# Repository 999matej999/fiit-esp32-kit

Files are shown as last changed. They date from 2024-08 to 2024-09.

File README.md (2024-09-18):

# FIIT ESP32 Kit
Board contains these components:
* 4x Buttons (needs internal pull-up resistor)
* 4x LED (red, yellow, green, blue)
* Programmable RGB LED
* Temperature & Humidity I<sup>2</sup>C Sensor AHT20
* Analog Light Sensor SFH320
* 2x QWIIC I<sup>2</sup>C connectors

For uploading code use USB UART by default.

## Pinout
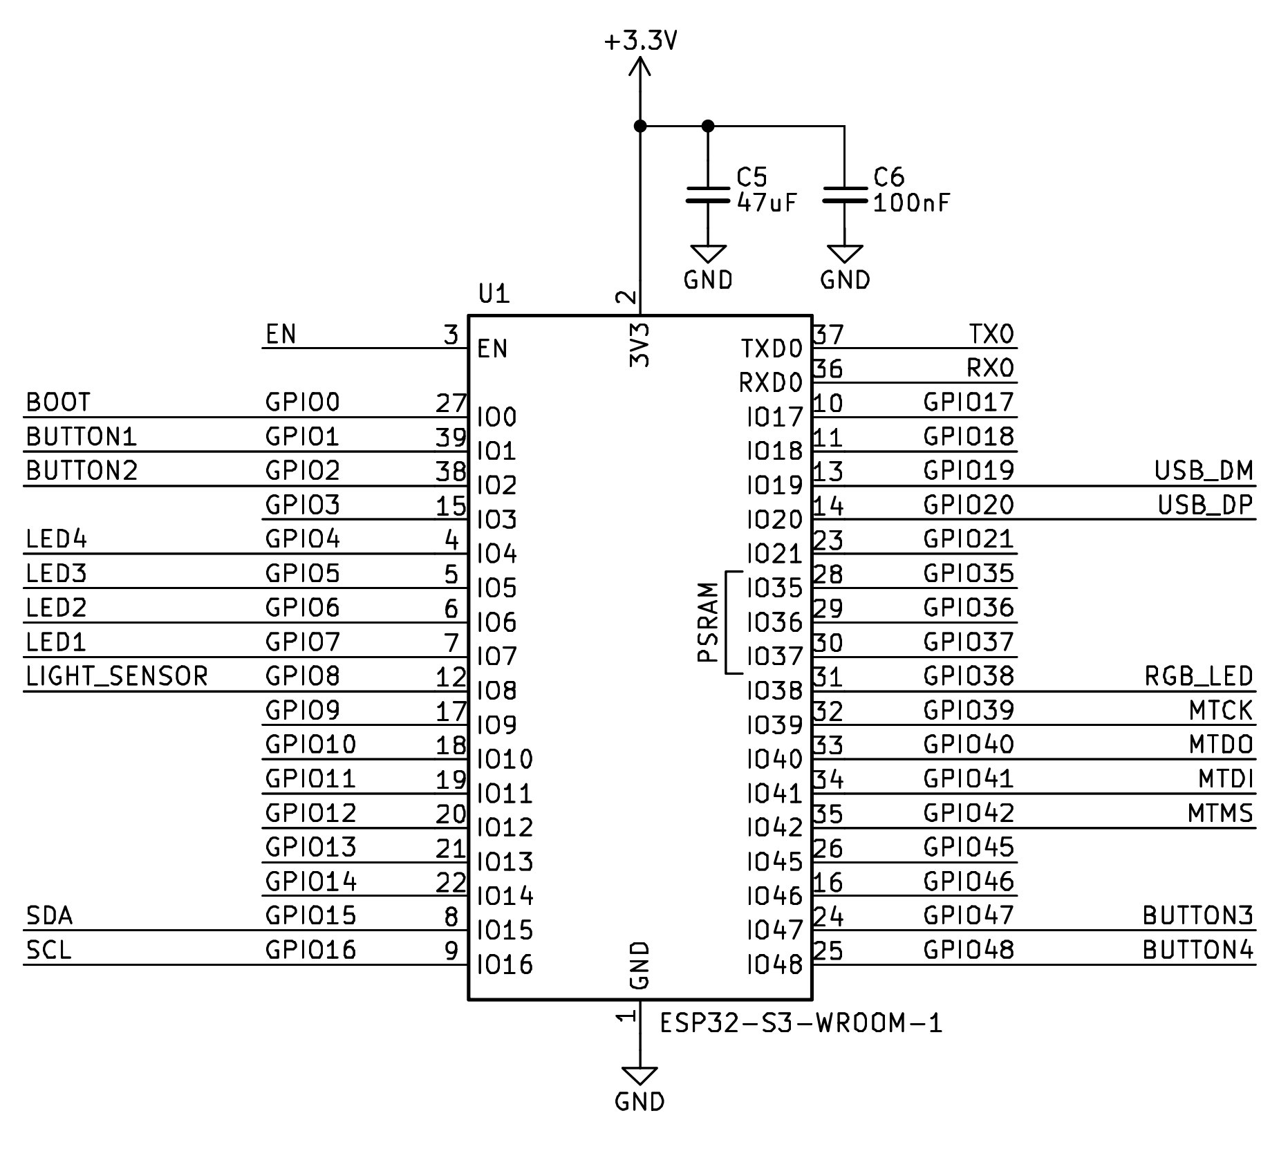
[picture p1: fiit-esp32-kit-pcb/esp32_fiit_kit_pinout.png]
pinout


GPIOX represents the pin marking, where X is the pin number that needs to be used in the Arduino IDE.

Please consider proper electrical connection to prevent electrical shortcuts.

## Arduino IDE
First of all ensure you have Arduino IDE and [ESP32 boards](https://randomnerdtutorials.com/installing-the-esp32-board-in-arduino-ide-windows-instructions/) properly installed.
Select board: ESP32S3 Dev Module
For basic examples use default configuration.

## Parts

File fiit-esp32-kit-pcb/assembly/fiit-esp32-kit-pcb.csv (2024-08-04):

Comment | Designator | Footprint | LCSC
22uF | C1,C2,C8,C9,C15 | Capacitor_SMD:C_0603_1608Metric | C59461
100uF | C11 | Capacitor_SMD:C_1206_3216Metric | C15008
1uF | C12,C13 | Capacitor_SMD:C_0603_1608Metric | C15849
100nF | C3,C4,C6,C10,C14,C16 | Capacitor_SMD:C_0603_1608Metric | C14663
47uF | C5 | Capacitor_SMD:C_0805_2012Metric | C16780
22pF | C7 | Capacitor_SMD:C_0603_1608Metric | C1653
RED | D1 | LED_SMD:LED_0805_2012Metric | C2295
YELLOW | D2,D10,D11 | LED_SMD:LED_0805_2012Metric | C2296
SK6812MINI | D12 | LED_SMD:LED_SK6812MINI_PLCC4_3.5x3.5mm_P1.75mm | C2886570
BLUE | D4 | LED_SMD:LED_0805_2012Metric | C2293
GREEN | D3,D5 | LED_SMD:LED_0805_2012Metric | C2297
PRTR5V0U2X | D6,D7 | Package_TO_SOT_SMD:SOT-143 | C5337179
BAT60B | D8,D9 | Diode_SMD:D_SOD-323 | C3018529
Conn_01x22_Pin | J1,J2 | Connector_PinHeader_2.54mm:PinHeader_1x22_P2.54mm_Vertical | C7430378
Conn_ARM_JTAG_SWD_10 | J3 | Connector_PinHeader_1.27mm:PinHeader_2x05_P1.27mm_Vertical_SMD
Conn_01x06_Pin | J4 | Connector_PinHeader_1.27mm:PinHeader_2x03_P1.27mm_Vertical_SMD
USB_C_Receptacle_USB2.0 | J5,J6 | Connector_USB:USB_C_Receptacle_G-Switch_GT-USB-7010ASV | C2927038
QWIIC - I2C | J7,J8 | Connector_JST:JST_SH_SM04B-SRSS-TB_1x04-1MP_P1.00mm_Horizontal | C160404
MPL2016S2R2 | L1 | FIIT_Kit:INDC2116X100N | C42215
MMDT3904 | Q1 | Package_TO_SOT_SMD:SOT-363_SC-70-6 | C3018510
SFH320 | Q2 | FIIT_Kit:TEMT6000X01 | C94098
100k | R1 | Resistor_SMD:R_0603_1608Metric | C25803
22.1k | R14 | Resistor_SMD:R_0603_1608Metric | C25961
47.5k | R15 | Resistor_SMD:R_0603_1608Metric | C23061
10k | R2,R6,R7,R12,R13,R16,R19 | Resistor_SMD:R_0603_1608Metric | C25804
4.99k | R3 | Resistor_SMD:R_0603_1608Metric | C23046
1.1k | R4 | Resistor_SMD:R_0603_1608Metric | C22764
2.4k | R5,R17,R18 | Resistor_SMD:R_0603_1608Metric | C22940
5.1k | R8,R9,R10,R11 | Resistor_SMD:R_0603_1608Metric | C23186
2.4k | RN1 | Resistor_SMD:R_Array_Convex_4x0603 | C425225
100R | RN2 | Resistor_SMD:R_Array_Convex_4x0603 | C425240
SPST NO | SW1,SW2,SW3,SW4,SW5 | Button_Switch_SMD:SW_SPST_PTS647_Sx38 | C318884
+5V | TP1 | TestPoint:TestPoint_Pad_D1.5mm
+3.3V | TP2 | TestPoint:TestPoint_Pad_D1.5mm
SDA | TP3 | TestPoint:TestPoint_Pad_D1.5mm
SCL | TP4 | TestPoint:TestPoint_Pad_D1.5mm
GND | TP5 | TestPoint:TestPoint_Pad_D1.5mm
SERIAL-RX | TP6 | TestPoint:TestPoint_Pad_D1.5mm
SERIAL-TX | TP7 | TestPoint:TestPoint_Pad_D1.5mm
ESP32-S3-WROOM-1 | U1 | RF_Module:ESP32-S3-WROOM-1 | C2913205
SY8089AAAC | U2 | Package_TO_SOT_SMD:TSOT-23-5 | C78988
CP2102N-Axx-xQFN28 | U3 | Package_DFN_QFN:QFN-28-1EP_5x5mm_P0.5mm_EP3.35x3.35mm | C964632
AHT20 | U4 | FIIT_Kit:AHT20 | C2757850

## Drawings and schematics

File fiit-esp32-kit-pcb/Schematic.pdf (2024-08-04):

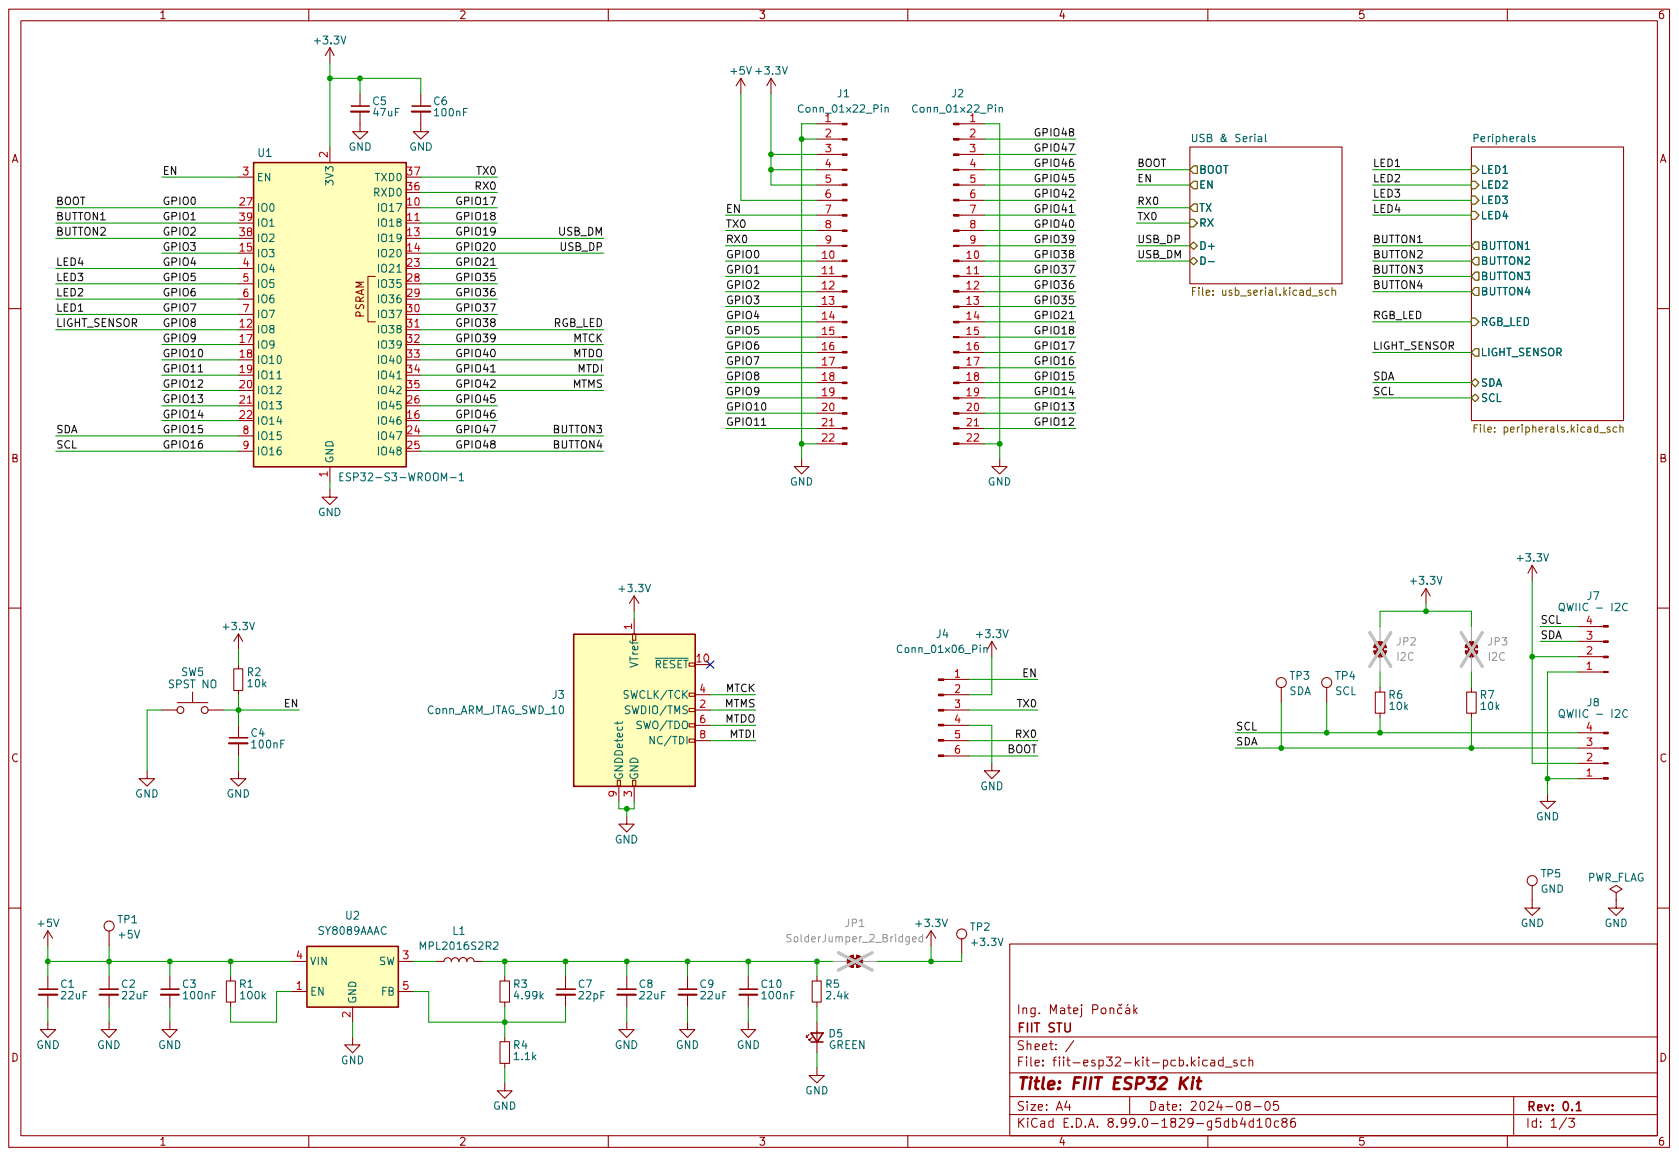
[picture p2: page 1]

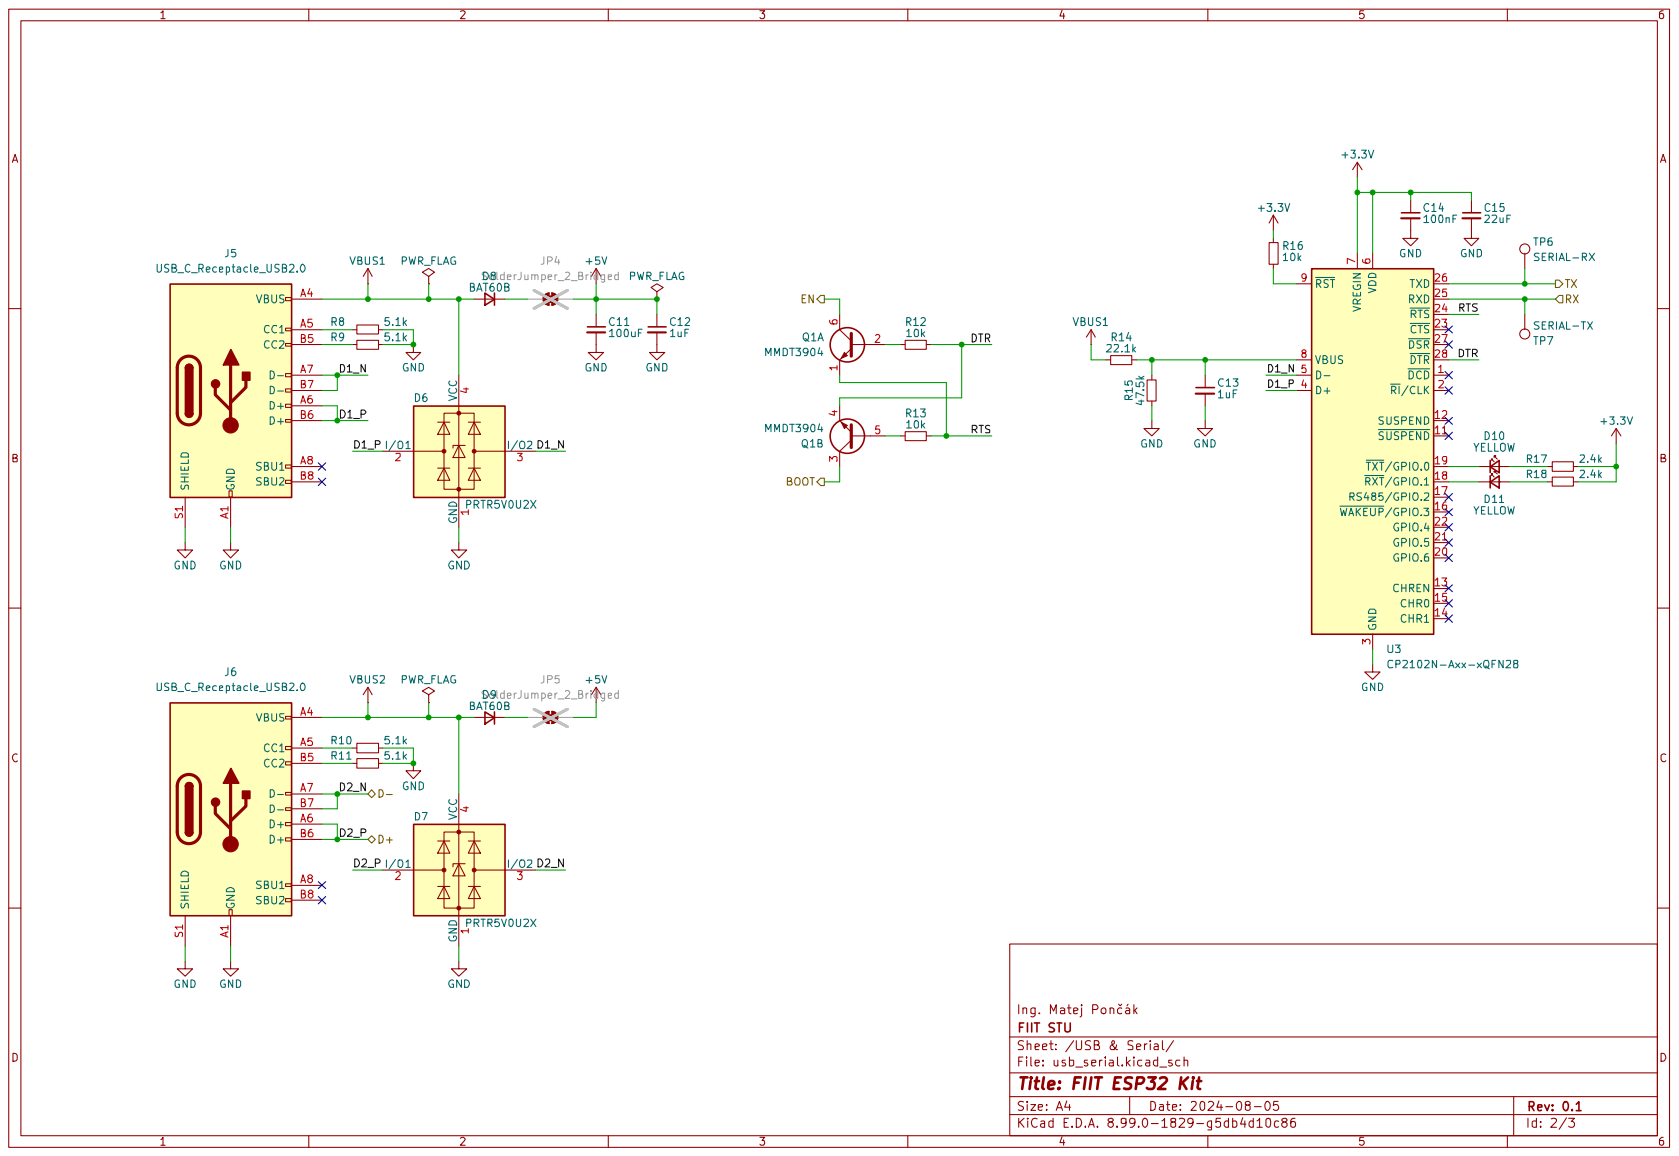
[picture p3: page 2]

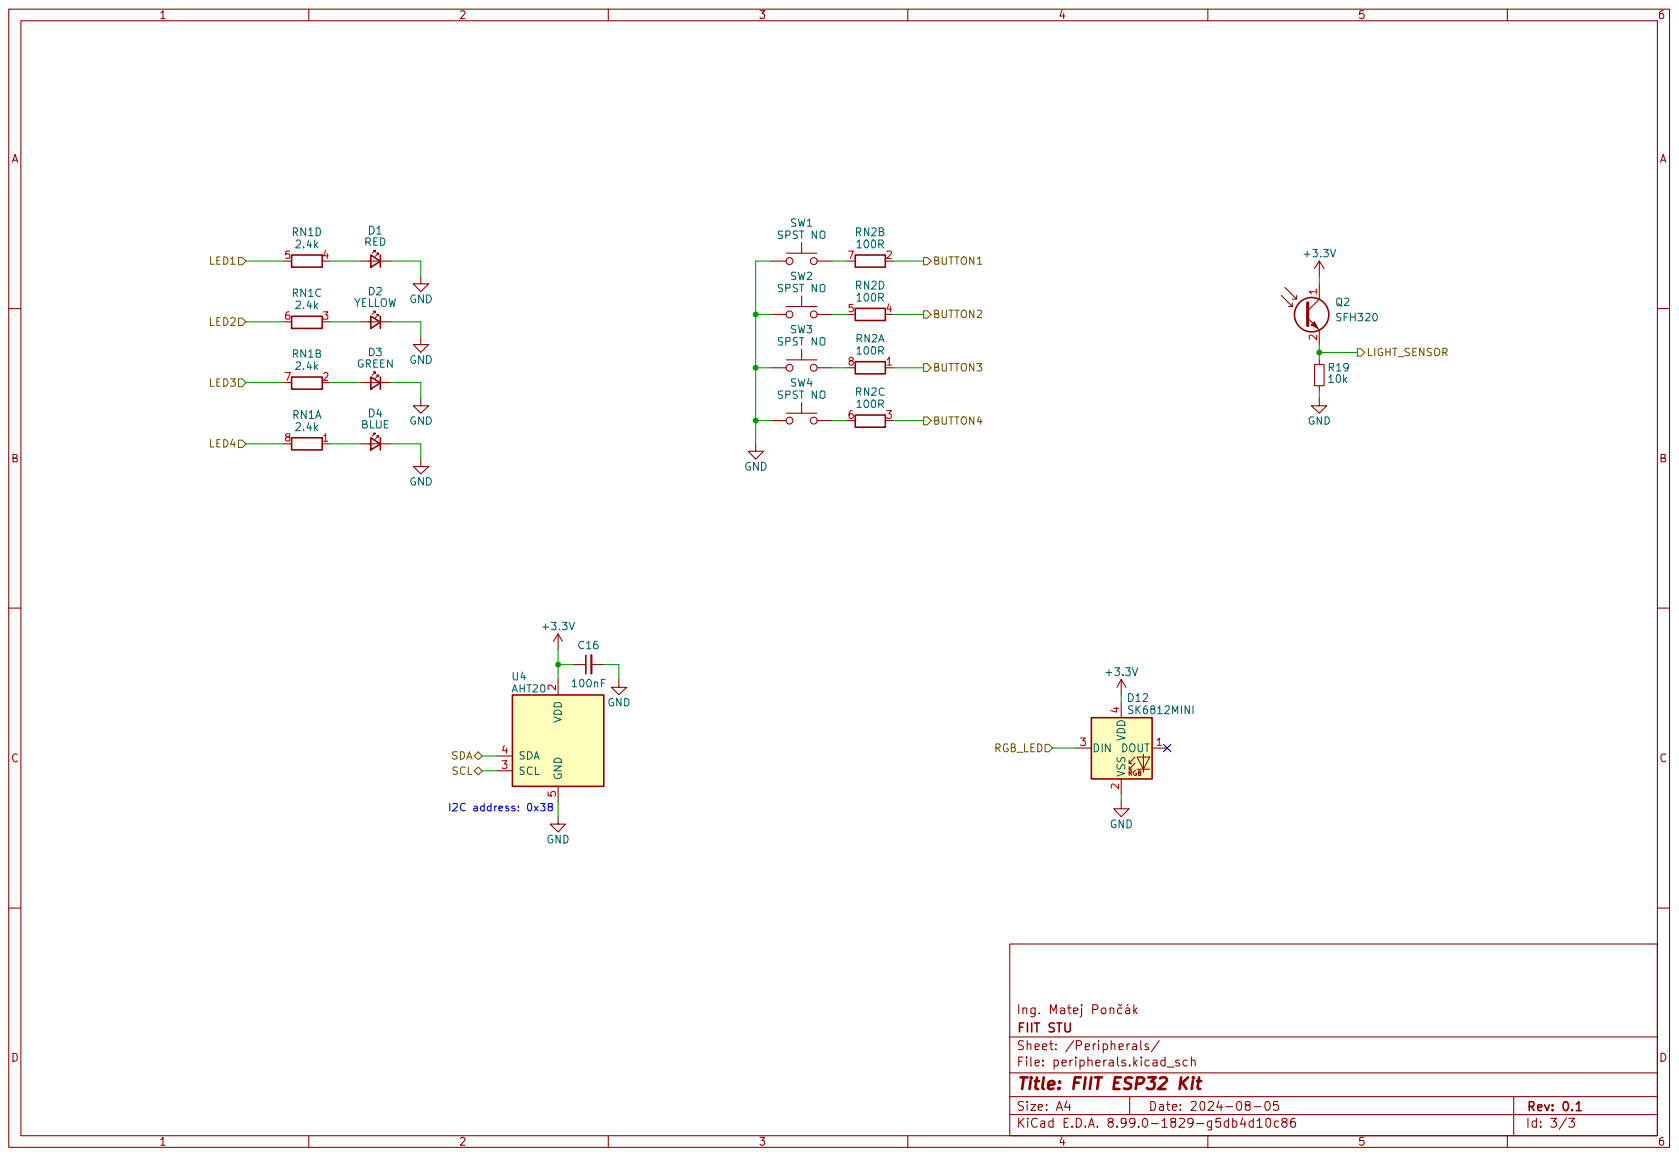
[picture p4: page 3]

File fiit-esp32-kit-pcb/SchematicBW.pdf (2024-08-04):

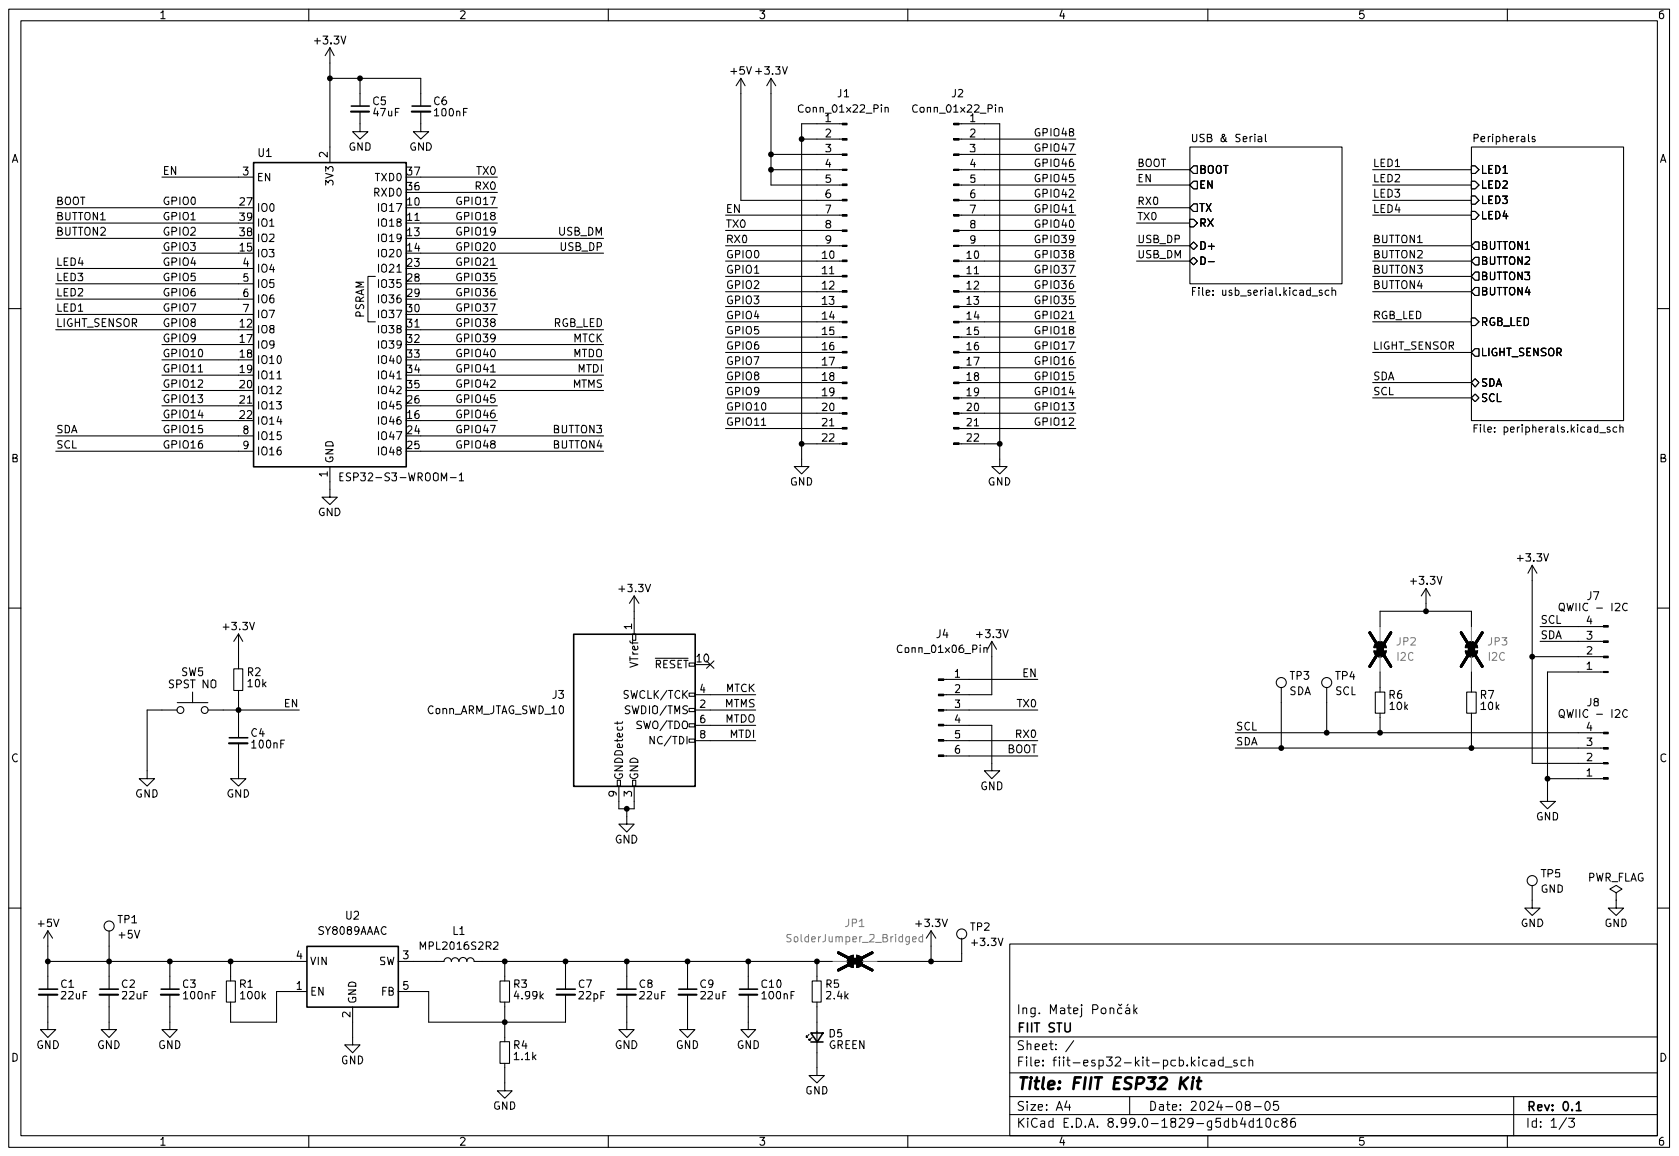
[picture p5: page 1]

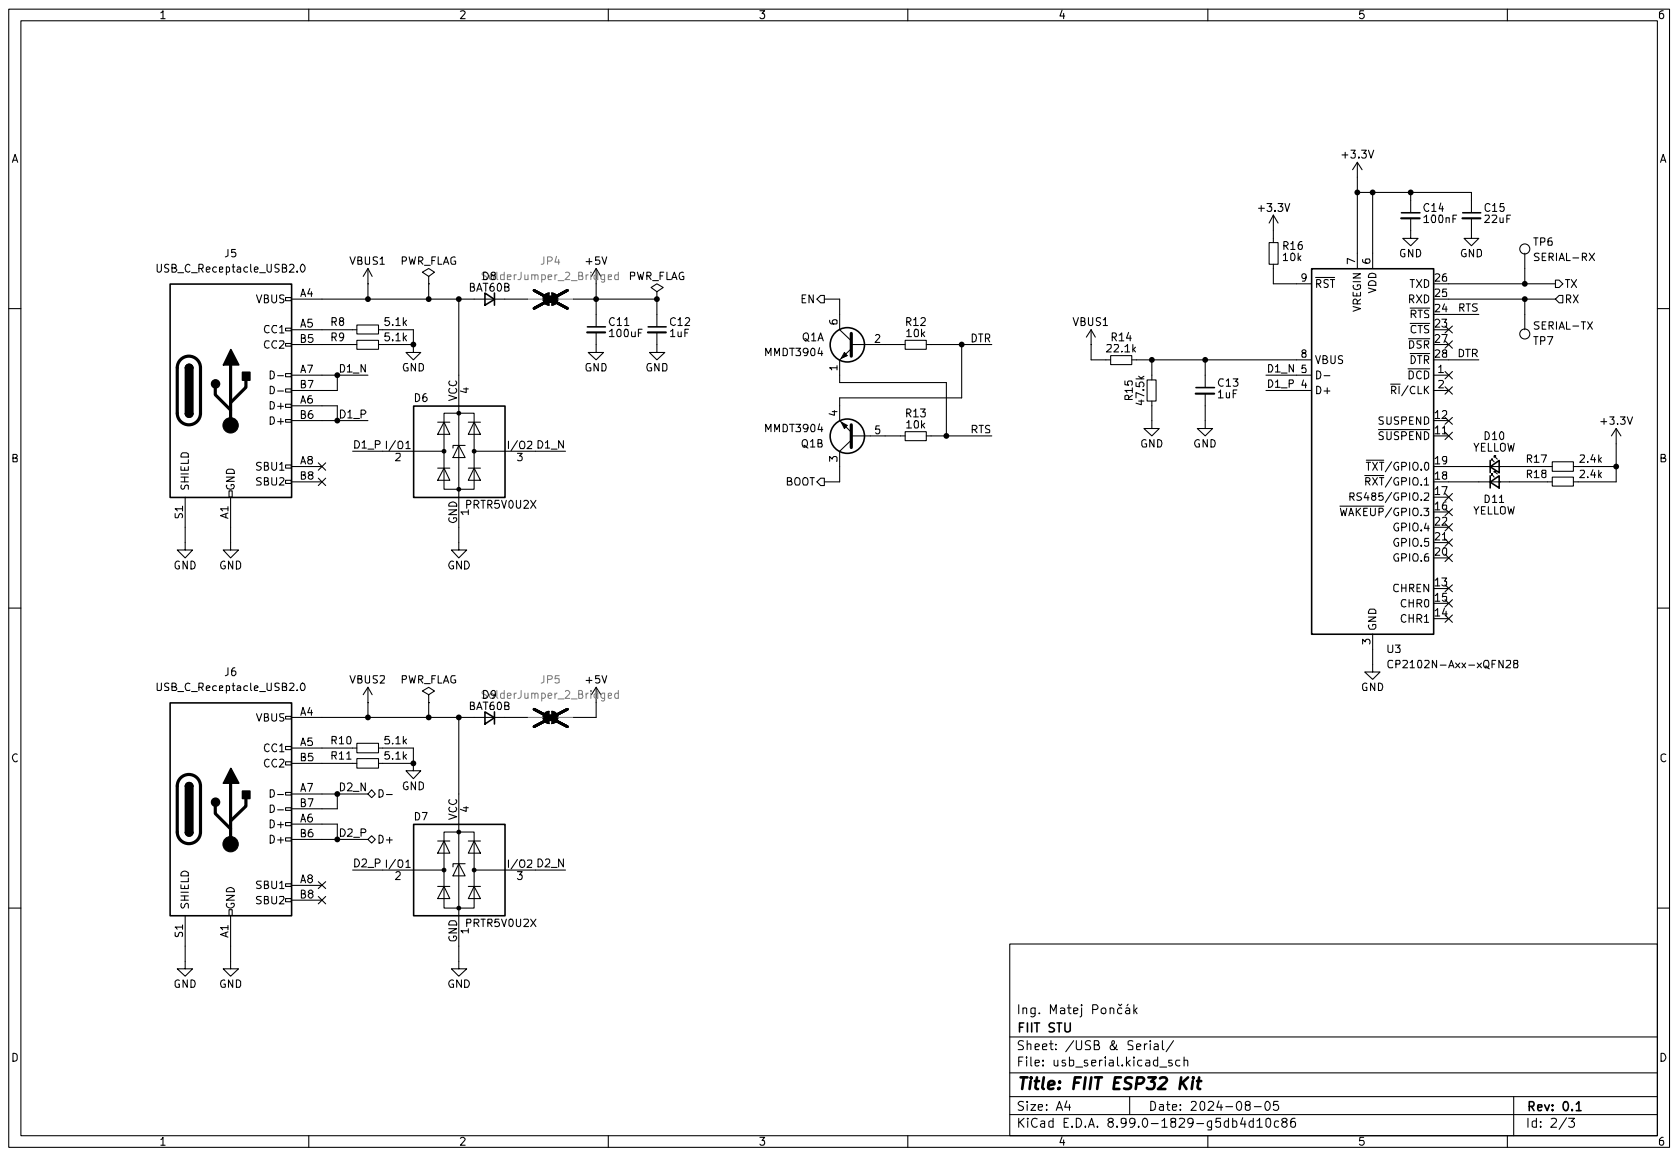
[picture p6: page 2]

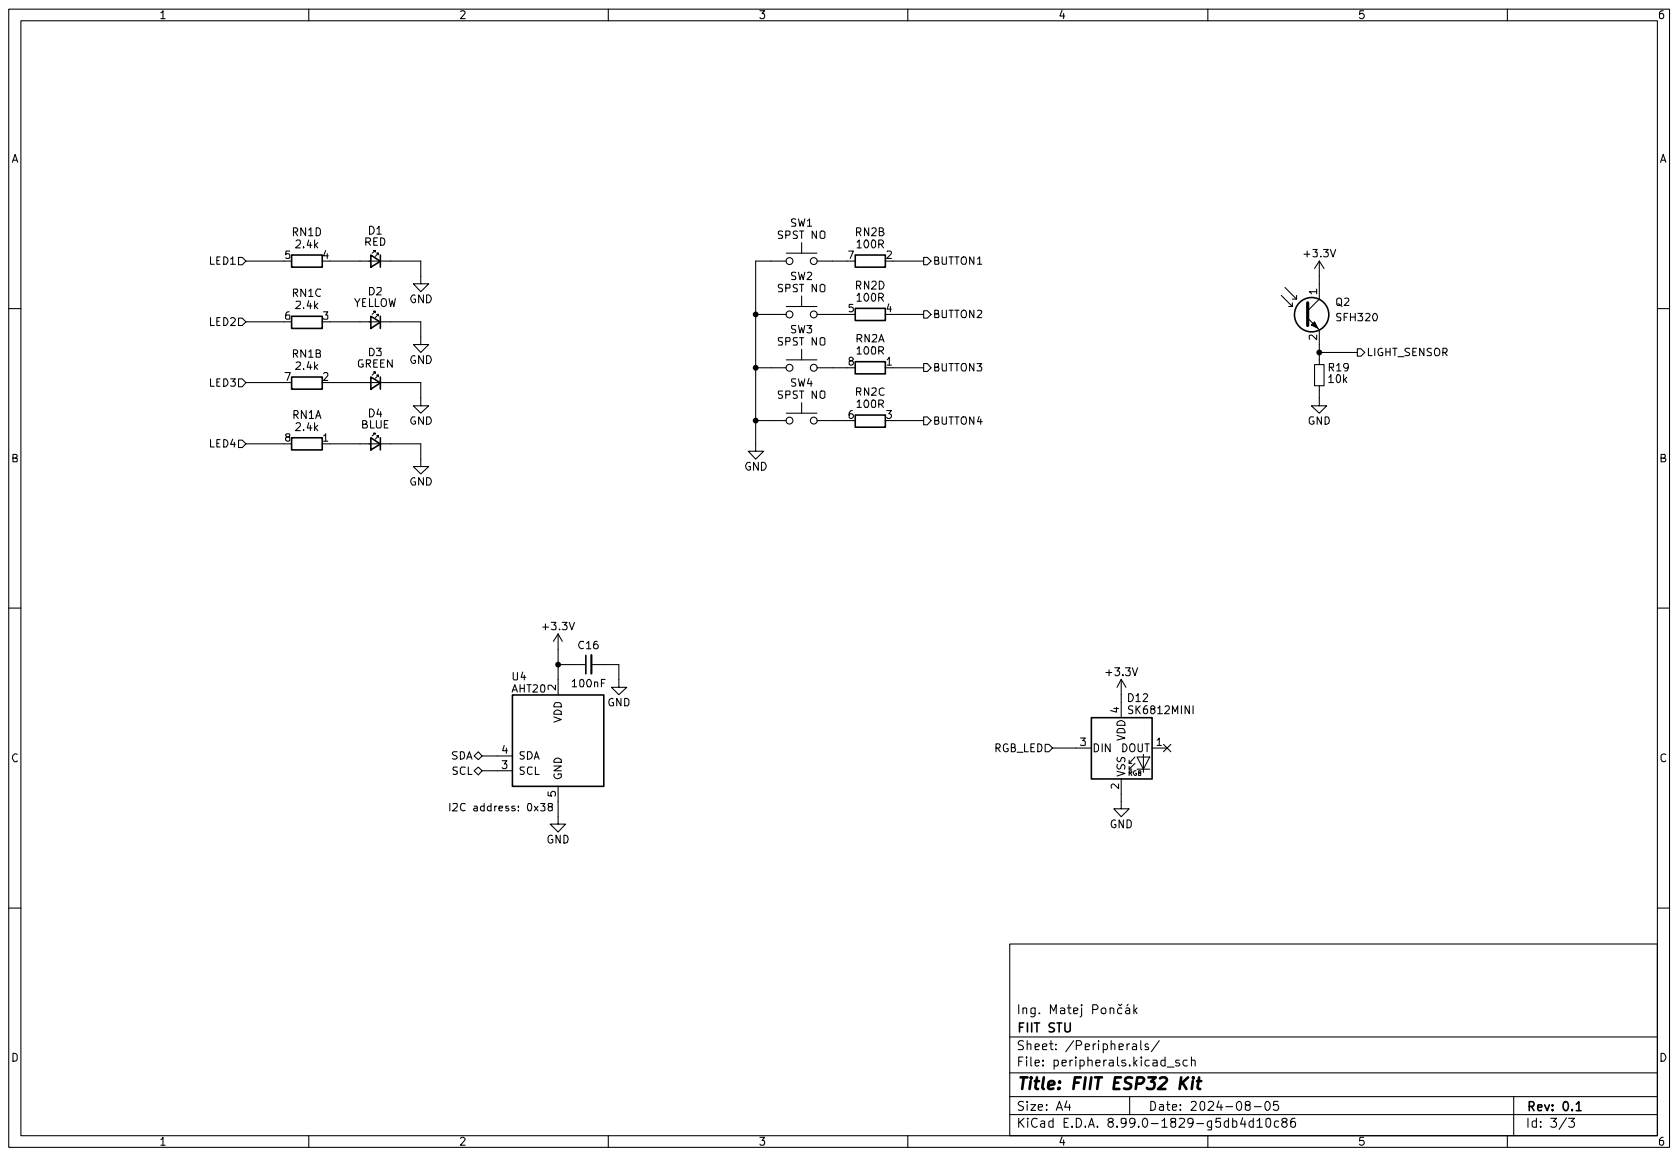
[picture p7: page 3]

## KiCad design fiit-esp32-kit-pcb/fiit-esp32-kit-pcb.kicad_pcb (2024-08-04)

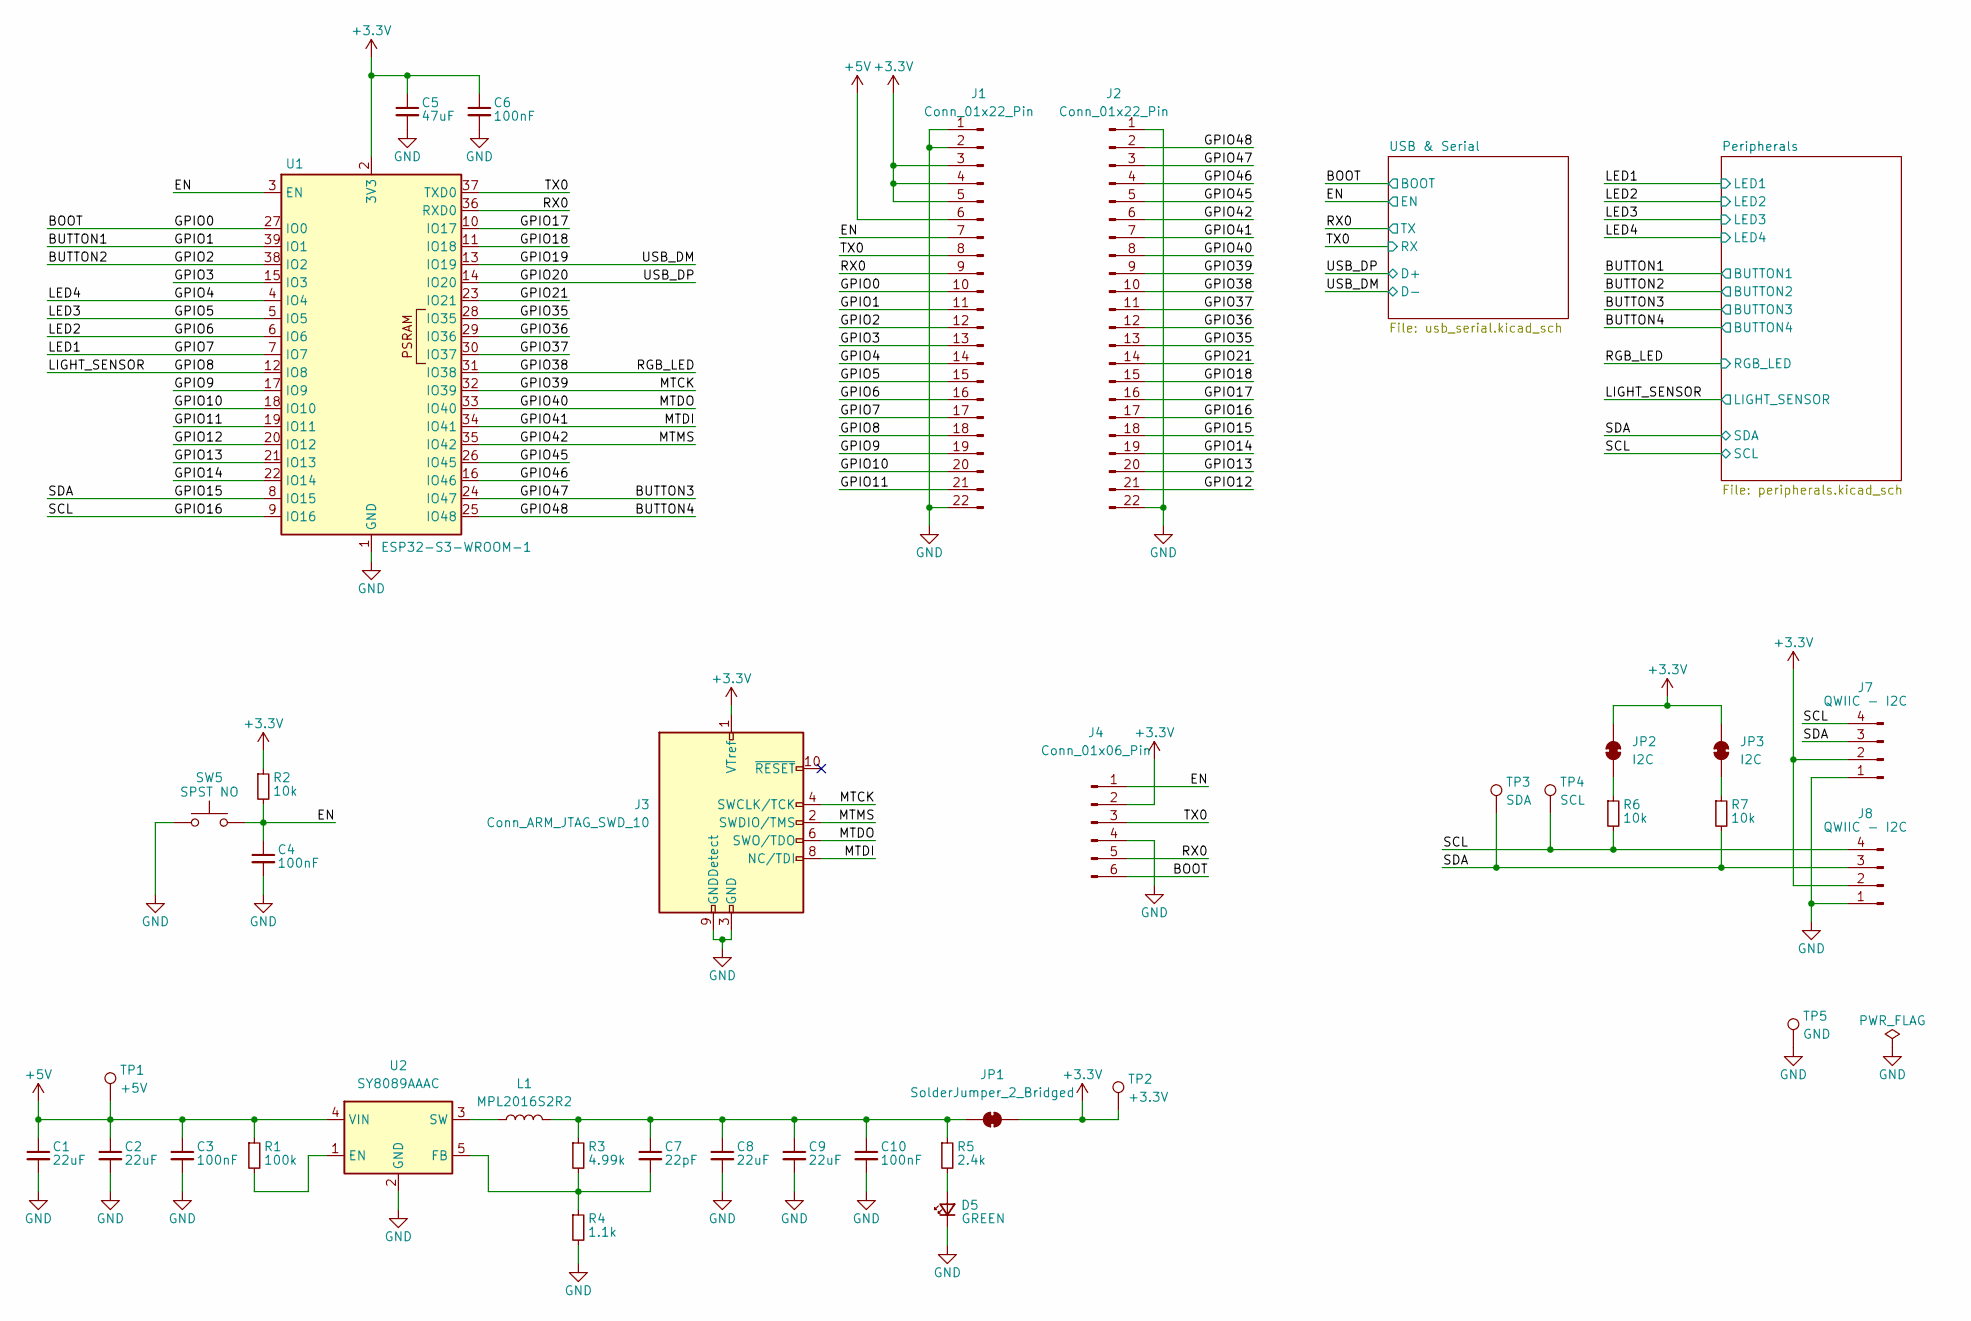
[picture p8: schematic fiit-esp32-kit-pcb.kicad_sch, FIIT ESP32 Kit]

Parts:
C1, C2, C8, C9: 22uF; C_0603_1608Metric; Manufacturer Part Number CL10A226MQ8NRNC; LCSC C59461
C3, C4, C6, C10: 100nF; C_0603_1608Metric; Manufacturer Part Number CC0603KRX7R9BB104; LCSC C14663
C5: 47uF; C_0805_2012Metric; Manufacturer Part Number CL21A476MQYNNNE; LCSC C16780
C7: 22pF; C_0603_1608Metric; Manufacturer Part Number CL10C220JB8NNNC; LCSC C1653
D5: GREEN; LED_0805_2012Metric; Manufacturer Part Number KT-0805G; LCSC C2297
J1, J2: Conn_01x22_Pin; PinHeader_1x22_P2.54mm_Vertical; Manufacturer Part Number DS1021-1x22SF11-B; LCSC C7430378
J3: Conn_ARM_JTAG_SWD_10; PinHeader_2x05_P1.27mm_Vertical_SMD
J4: Conn_01x06_Pin; PinHeader_2x03_P1.27mm_Vertical_SMD
J7, J8: QWIIC - I2C; JST_SH_SM04B-SRSS-TB_1x04-1MP_P1.00mm_Horizontal; Manufacturer Part Number SM04B-SRSS-TB(LF)(SN); LCSC C160404
JP1: SolderJumper_2_Bridged; SolderJumper-2_P1.3mm_Bridged_RoundedPad1.0x1.5mm
JP2, JP3: I2C; SolderJumper-2_P1.3mm_Bridged_RoundedPad1.0x1.5mm
L1: MPL2016S2R2; INDC2116X100N; Manufacturer Part Number MPL2016S2R2MHT; LCSC C42215
R1: 100k; R_0603_1608Metric; Manufacturer Part Number 0603WAF1003T5E; LCSC C25803
R2, R6, R7: 10k; R_0603_1608Metric; Manufacturer Part Number 0603WAF1002T5E; LCSC C25804
R3: 4.99k; R_0603_1608Metric; Manufacturer Part Number 0603WAF4991T5E; LCSC C23046
R4: 1.1k; R_0603_1608Metric; Manufacturer Part Number 0603WAF1101T5E; LCSC C22764
R5: 2.4k; R_0603_1608Metric; Manufacturer Part Number 0603WAF2401T5E; LCSC C22940
SW5: SPST NO; SW_SPST_PTS647_Sx38; Manufacturer Part Number TS-1187A-B-A-B; LCSC C318884
TP1: +5V; TestPoint_Pad_D1.5mm
TP2: +3.3V; TestPoint_Pad_D1.5mm
TP3: SDA; TestPoint_Pad_D1.5mm
TP4: SCL; TestPoint_Pad_D1.5mm
TP5: GND; TestPoint_Pad_D1.5mm
U1: ESP32-S3-WROOM-1; Manufacturer Part Number ESP32-S3-WROOM-1-N16R2; LCSC C2913205
U2: SY8089AAAC; TSOT-23-5; Manufacturer Part Number SY8089AAAC; LCSC C78988

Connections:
+3.3V: C5.1, C6.1, J1.3, J1.4, J1.5, J3.1 (VTref), J4.2, J7.2, J8.2, JP1.2 (B), JP2.2 (B), JP3.2 (B), R2.1, TP2.1, U1.2 (3V3); also elsewhere on the board
+5V: C1.1, C2.1, C3.1, J1.6, R1.1, TP1.1, U2.4 (VIN); also elsewhere on the board
/BOOT: J1.10, J4.6, U1.27 (IO0); also elsewhere on the board
/BUTTON1: J1.11, U1.39 (IO1); also elsewhere on the board
/BUTTON2: J1.12, U1.38 (IO2); also elsewhere on the board
/BUTTON3: J2.3, U1.24 (IO47); also elsewhere on the board
/BUTTON4: J2.2, U1.25 (IO48); also elsewhere on the board
/EN: C4.1, J1.7, J4.1, R2.2, SW5.2, U1.3 (EN); also elsewhere on the board
/GPIO3: J1.13, U1.15 (IO3)
/GPIO4: J1.14, U1.4 (IO4); also elsewhere on the board
/GPIO5: J1.15, U1.5 (IO5); also elsewhere on the board
/GPIO6: J1.16, U1.6 (IO6); also elsewhere on the board
/GPIO7: J1.17, U1.7 (IO7); also elsewhere on the board
/GPIO8: J1.18, U1.12 (IO8); also elsewhere on the board
/GPIO9: J1.19, U1.17 (IO9)
/GPIO10: J1.20, U1.18 (IO10)
/GPIO11: J1.21, U1.19 (IO11)
/GPIO12: J2.21, U1.20 (IO12)
/GPIO13: J2.20, U1.21 (IO13)
/GPIO14: J2.19, U1.22 (IO14)
/GPIO15: J2.18, J7.3, J8.3, R7.2, TP3.1, U1.8 (IO15); also elsewhere on the board
/GPIO16: J2.17, J7.4, J8.4, R6.2, TP4.1, U1.9 (IO16); also elsewhere on the board
/GPIO17: J2.16, U1.10 (IO17)
/GPIO18: J2.15, U1.11 (IO18)
/GPIO19: U1.13 (IO19); also elsewhere on the board
/GPIO20: U1.14 (IO20); also elsewhere on the board
/GPIO21: J2.14, U1.23 (IO21)
/GPIO35: J2.13, U1.28 (IO35)
/GPIO36: J2.12, U1.29 (IO36)
/GPIO37: J2.11, U1.30 (IO37)
/GPIO38: J2.10, U1.31 (IO38); also elsewhere on the board
/GPIO39: J2.9, J3.4 (SWCLK/TCK), U1.32 (IO39)
/GPIO40: J2.8, J3.6 (SWO/TDO), U1.33 (IO40)
/GPIO41: J2.7, J3.8 (NC/TDI), U1.34 (IO41)
/GPIO42: J2.6, J3.2 (SWDIO/TMS), U1.35 (IO42)
/GPIO45: J2.5, U1.26 (IO45)
/GPIO46: J2.4, U1.16 (IO46)
/RX0: J1.9, J4.5, U1.36 (RXD0); also elsewhere on the board
/TX0: J1.8, J4.3, U1.37 (TXD0); also elsewhere on the board
GND: C1.2, C2.2, C3.2, C4.2, C5.2, C6.2, C8.2, C9.2, C10.2, D5.1 (K), J1.1, J1.2, J1.22, J2.1, J2.22, J3.3 (GND), J3.5 (GND), J3.9 (GNDDetect), J4.4, J7.1, J8.1, R4.2, SW5.1, TP5.1, U1.1 (GND), U1.40 (GND), U1.41 (GND), U2.2 (GND); also elsewhere on the board
unnamed: D5.2 (A), R5.2
unnamed: C7.1, C8.1, C9.1, C10.1, JP1.1 (A), L1.2, R3.1, R5.1
unnamed: JP2.1 (A), R6.1
unnamed: JP3.1 (A), R7.1
unnamed: R1.2, U2.1 (EN)
unnamed: C7.2, R3.2, R4.1, U2.5 (FB)
unnamed: L1.1, U2.3 (SW)

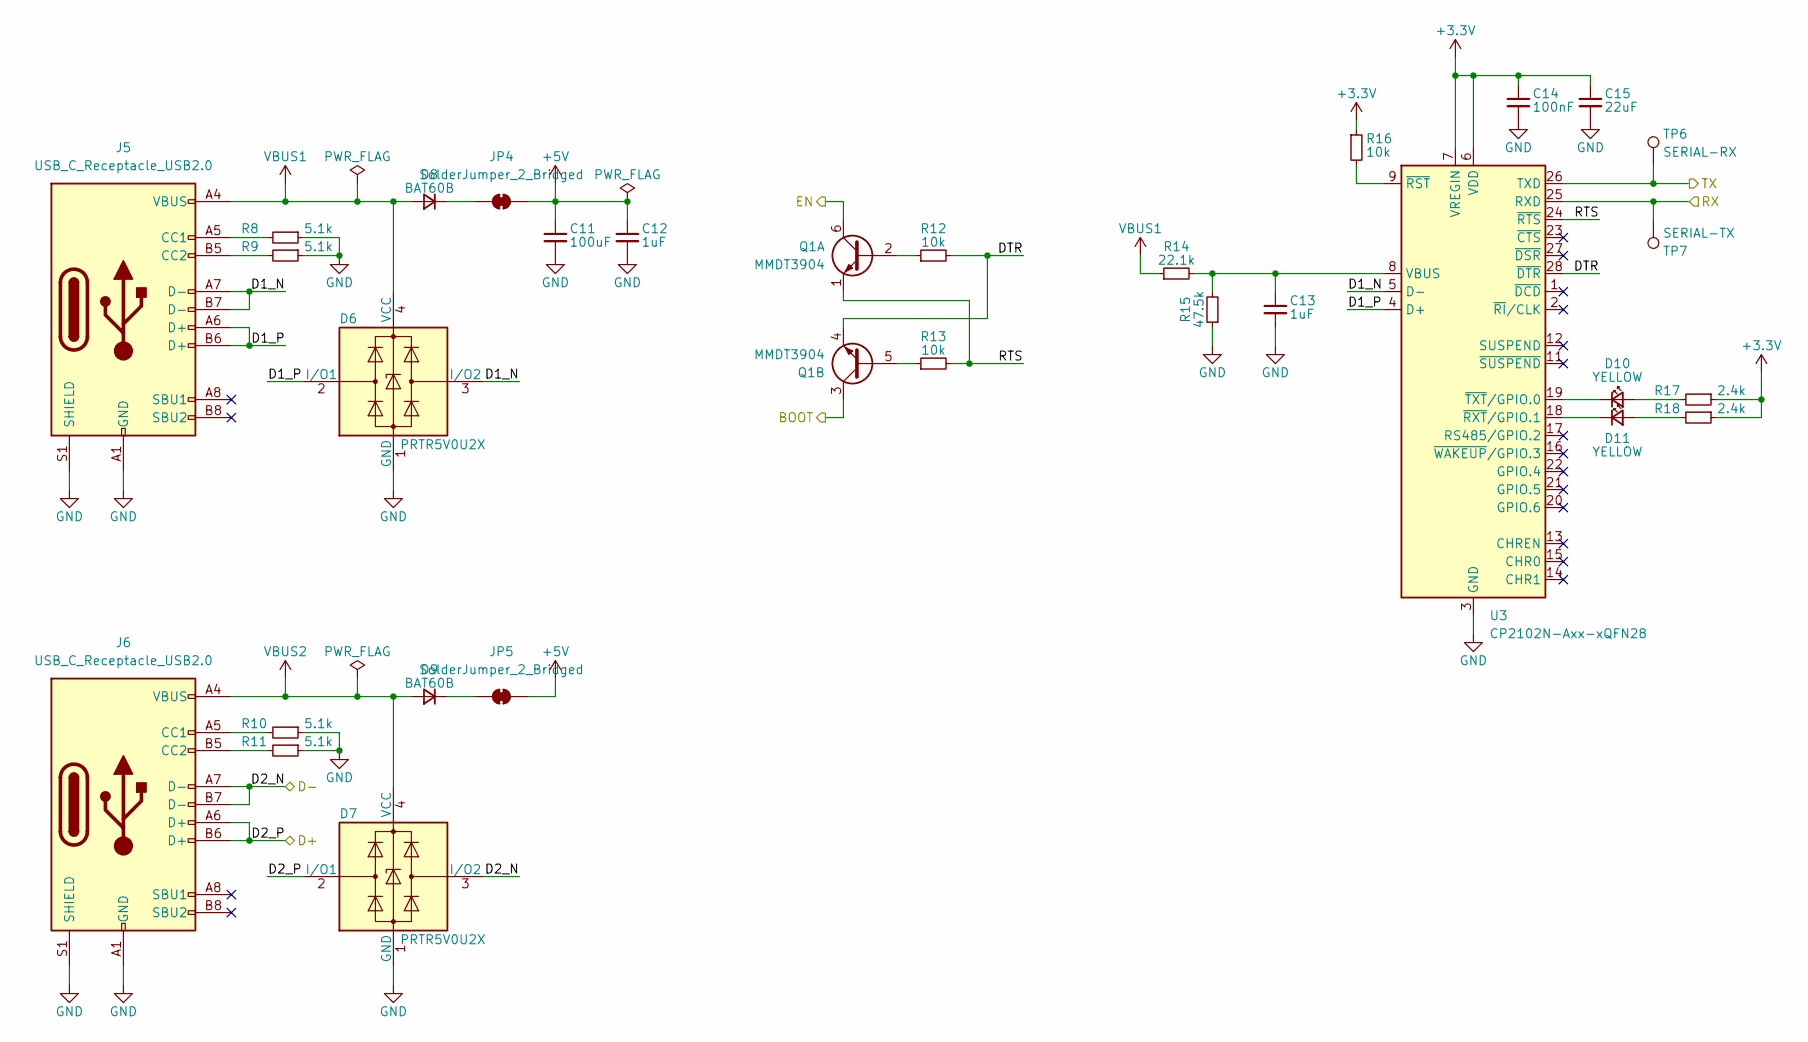
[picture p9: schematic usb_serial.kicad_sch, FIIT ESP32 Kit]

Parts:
C11: 100uF; C_1206_3216Metric; Manufacturer Part Number CL31A107MQHNNNE; LCSC C15008
C12, C13: 1uF; C_0603_1608Metric; Manufacturer Part Number CL10A105KB8NNNC; LCSC C15849
C14: 100nF; C_0603_1608Metric; Manufacturer Part Number CC0603KRX7R9BB104; LCSC C14663
C15: 22uF; C_0603_1608Metric; Manufacturer Part Number CL10A226MQ8NRNC; LCSC C59461
D6, D7: PRTR5V0U2X; SOT-143; Manufacturer Part Number PRTR5V0U2X-HXY; LCSC C5337179
D8, D9: BAT60B; D_SOD-323; Manufacturer Part Number BAT60B; LCSC C3018529
D10, D11: YELLOW; LED_0805_2012Metric; Manufacturer Part Number KT-0805Y; LCSC C2296
J5, J6: USB_C_Receptacle_USB2.0; USB_C_Receptacle_G-Switch_GT-USB-7010ASV; Manufacturer Part Number USB-TYPE-C-018; LCSC C2927038
JP4, JP5: SolderJumper_2_Bridged; SolderJumper-2_P1.3mm_Bridged_RoundedPad1.0x1.5mm
Q1: MMDT3904; SOT-363_SC-70-6; Manufacturer Part Number MMDT3904; LCSC C3018510
R8, R9, R10, R11: 5.1k; R_0603_1608Metric; Manufacturer Part Number 0603WAF5101T5E; LCSC C23186
R12, R13, R16: 10k; R_0603_1608Metric; Manufacturer Part Number 0603WAF1002T5E; LCSC C25804
R14: 22.1k; R_0603_1608Metric; Manufacturer Part Number 0603WAF2212T5E; LCSC C25961
R15: 47.5k; R_0603_1608Metric; Manufacturer Part Number 0603WAF4752T5E; LCSC C23061
R17, R18: 2.4k; R_0603_1608Metric; Manufacturer Part Number 0603WAF2401T5E; LCSC C22940
TP6: SERIAL-RX; TestPoint_Pad_D1.5mm
TP7: SERIAL-TX; TestPoint_Pad_D1.5mm
U3: CP2102N-Axx-xQFN28; QFN-28-1EP_5x5mm_P0.5mm_EP3.35x3.35mm; Manufacturer Part Number CP2102N-A02-GQFN28R; LCSC C964632

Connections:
+3.3V: C14.1, C15.1, R16.1, R17.1, R18.1, U3.6 (VDD), U3.7 (VREGIN); also elsewhere on the board
+5V: C11.1, C12.1, JP4.2 (B), JP5.2 (B); also elsewhere on the board
/BOOT: Q1.3 (C2); also elsewhere on the board
/EN: Q1.6 (C1); also elsewhere on the board
/GPIO19: D7.3 (I/O2), J6.A7 (D-), J6.B7 (D-); also elsewhere on the board
/GPIO20: D7.2 (I/O1), J6.A6 (D+), J6.B6 (D+); also elsewhere on the board
/RX0: TP6.1, U3.26 (TXD); also elsewhere on the board
/TX0: TP7.1, U3.25 (RXD); also elsewhere on the board
/USB & Serial/D1_N: D6.3 (I/O2), J5.A7 (D-), J5.B7 (D-), U3.5 (D-)
/USB & Serial/D1_P: D6.2 (I/O1), J5.A6 (D+), J5.B6 (D+), U3.4 (D+)
/USB & Serial/DTR: Q1.4 (E2), R12.2, U3.28 (~DTR)
/USB & Serial/RTS: Q1.1 (E1), R13.2, U3.24 (~RTS)
GND: C11.2, C12.2, C13.2, C14.2, C15.2, D6.1 (GND), D7.1 (GND), J5.A1 (GND), J5.A12 (GND), J5.B1 (GND), J5.B12 (GND), J5.S1 (SHIELD), J6.A1 (GND), J6.A12 (GND), J6.B1 (GND), J6.B12 (GND), J6.S1 (SHIELD), R8.1, R9.1, R10.1, R11.1, R15.1, U3.3 (GND), U3.29 (GND); also elsewhere on the board
unnamed: D8.1 (K), JP4.1 (A)
unnamed: D9.1 (K), JP5.1 (A)
unnamed: D10.2 (A), R17.2
unnamed: D10.1 (K), U3.19 (~TXT/GPIO.0)
unnamed: D11.2 (A), R18.2
unnamed: D11.1 (K), U3.18 (~RXT/GPIO.1)
unnamed: J5.A5 (CC1), R8.2
unnamed: J5.B5 (CC2), R9.2
unnamed: J6.A5 (CC1), R10.2
unnamed: J6.B5 (CC2), R11.2
unnamed: Q1.2 (B1), R12.1
unnamed: Q1.5 (B2), R13.1
unnamed: C13.1, R14.2, R15.2, U3.8 (VBUS)
unnamed: R16.2, U3.9 (~RST)
VBUS1: D6.4 (VCC), D8.2 (A), J5.A4 (VBUS), J5.A9 (VBUS), J5.B4 (VBUS), J5.B9 (VBUS), R14.1
VBUS2: D7.4 (VCC), D9.2 (A), J6.A4 (VBUS), J6.A9 (VBUS), J6.B4 (VBUS), J6.B9 (VBUS)

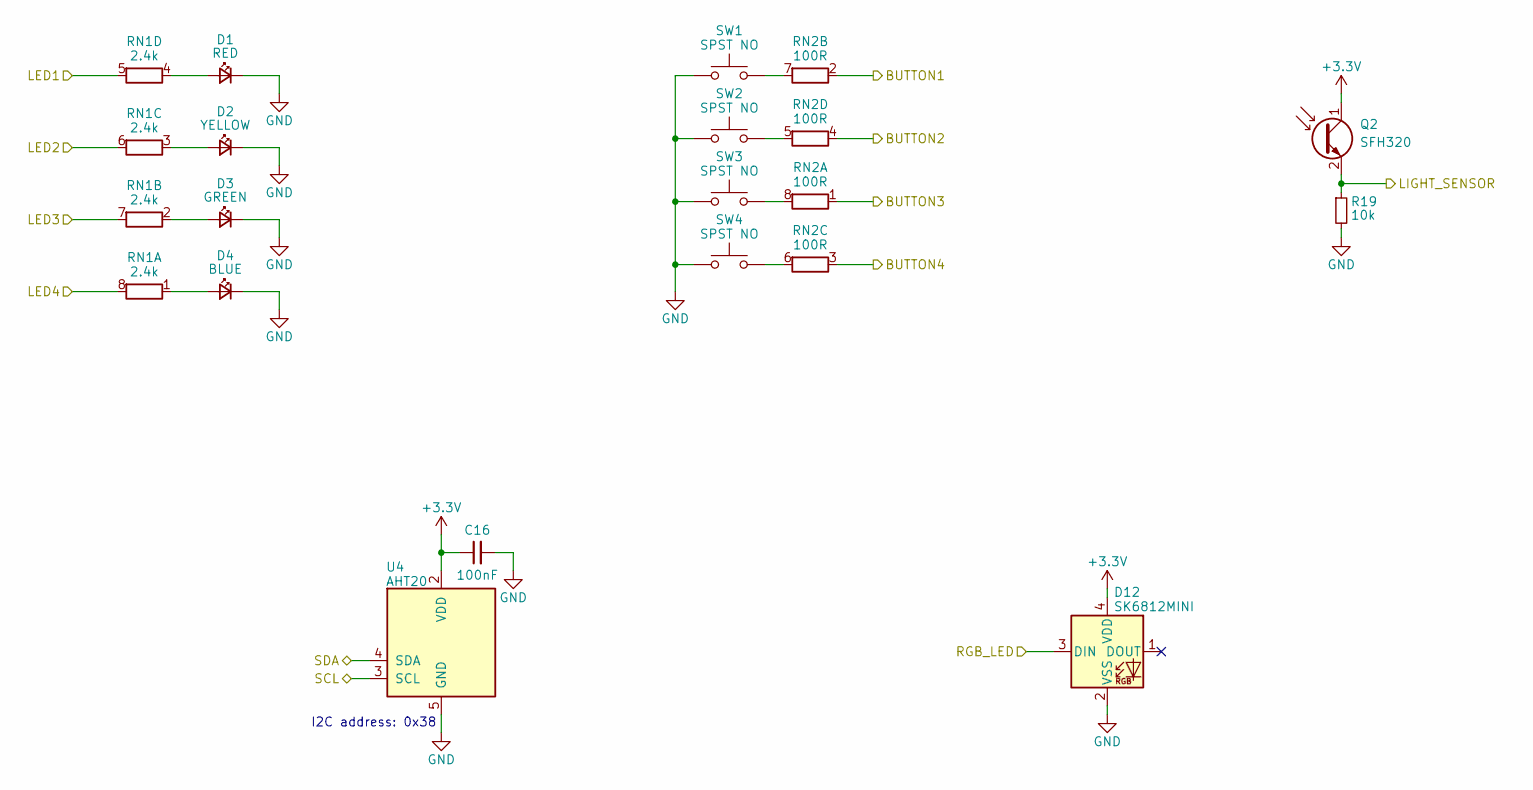
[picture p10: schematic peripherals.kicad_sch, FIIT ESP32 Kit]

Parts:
C16: 100nF; C_0603_1608Metric; Manufacturer Part Number CC0603KRX7R9BB104; LCSC C14663
D1: RED; LED_0805_2012Metric; Manufacturer Part Number KT-0805R; LCSC C2295
D2: YELLOW; LED_0805_2012Metric; Manufacturer Part Number KT-0805Y; LCSC C2296
D3: GREEN; LED_0805_2012Metric; Manufacturer Part Number KT-0805G; LCSC C2297
D4: BLUE; LED_0805_2012Metric; Manufacturer Part Number KT-0805B; LCSC C2293
D12: SK6812MINI; LED_SK6812MINI_PLCC4_3.5x3.5mm_P1.75mm; Manufacturer Part Number SK6812mini; LCSC C2886570
Q2: SFH320; TEMT6000X01; Manufacturer Part Number TEMT6000X01; LCSC C94098
R19: 10k; R_0603_1608Metric; Manufacturer Part Number 0603WAF1002T5E; LCSC C25804
RN1: 2.4k; R_Array_Convex_4x0603; Manufacturer Part Number 4D03WGF2401T5E; LCSC C425225
RN2: 100R; R_Array_Convex_4x0603; Manufacturer Part Number 4D03WGF1000T5E; LCSC C425240
SW1, SW2, SW3, SW4: SPST NO; SW_SPST_PTS647_Sx38; Manufacturer Part Number TS-1187A-B-A-B; LCSC C318884
U4: AHT20; Manufacturer Part Number AHT20; LCSC C2757850

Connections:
+3.3V: C16.1, D12.4 (VDD), Q2.1 (C), U4.2 (VDD); also elsewhere on the board
/BUTTON1: RN2.2 (R2.1); also elsewhere on the board
/BUTTON2: RN2.4 (R4.1); also elsewhere on the board
/BUTTON3: RN2.1 (R1.1); also elsewhere on the board
/BUTTON4: RN2.3 (R3.1); also elsewhere on the board
/GPIO4: RN1.8 (R1.2); also elsewhere on the board
/GPIO5: RN1.7 (R2.2); also elsewhere on the board
/GPIO6: RN1.6 (R3.2); also elsewhere on the board
/GPIO7: RN1.5 (R4.2); also elsewhere on the board
/GPIO8: Q2.2 (E), R19.1; also elsewhere on the board
/GPIO15: U4.4 (SDA); also elsewhere on the board
/GPIO16: U4.3 (SCL); also elsewhere on the board
/GPIO38: D12.3 (DIN); also elsewhere on the board
GND: C16.2, D1.1 (K), D2.1 (K), D3.1 (K), D4.1 (K), D12.2 (VSS), R19.2, SW1.1, SW2.1, SW3.1, SW4.1, U4.5 (GND); also elsewhere on the board
unnamed: D1.2 (A), RN1.4 (R4.1)
unnamed: D2.2 (A), RN1.3 (R3.1)
unnamed: D3.2 (A), RN1.2 (R2.1)
unnamed: D4.2 (A), RN1.1 (R1.1)
unnamed: RN2.8 (R1.2), SW3.2
unnamed: RN2.7 (R2.2), SW1.2
unnamed: RN2.6 (R3.2), SW4.2
unnamed: RN2.5 (R4.2), SW2.2

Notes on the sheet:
I2C address: 0x38

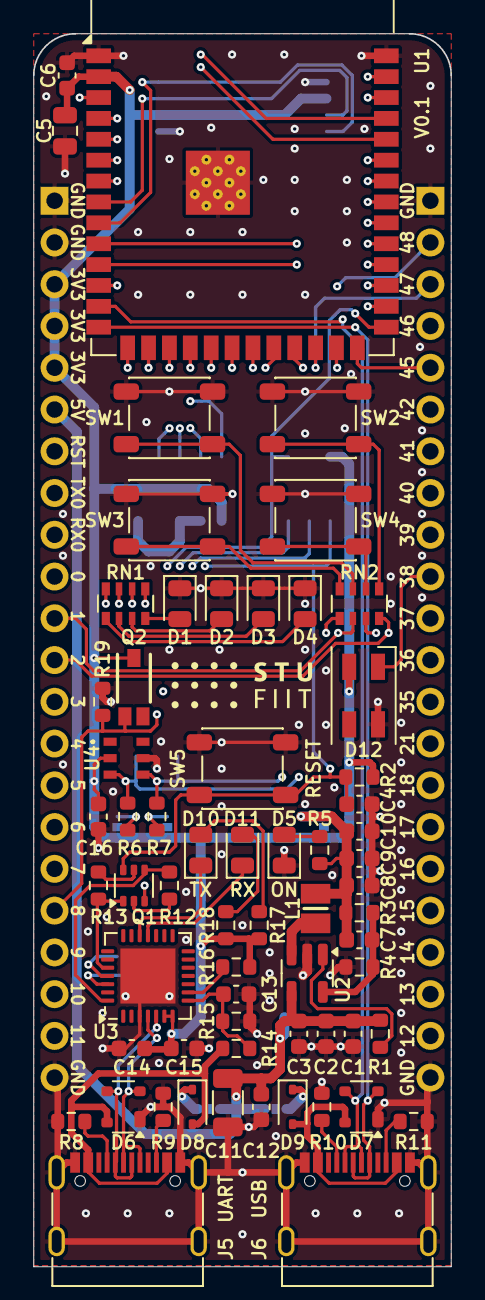
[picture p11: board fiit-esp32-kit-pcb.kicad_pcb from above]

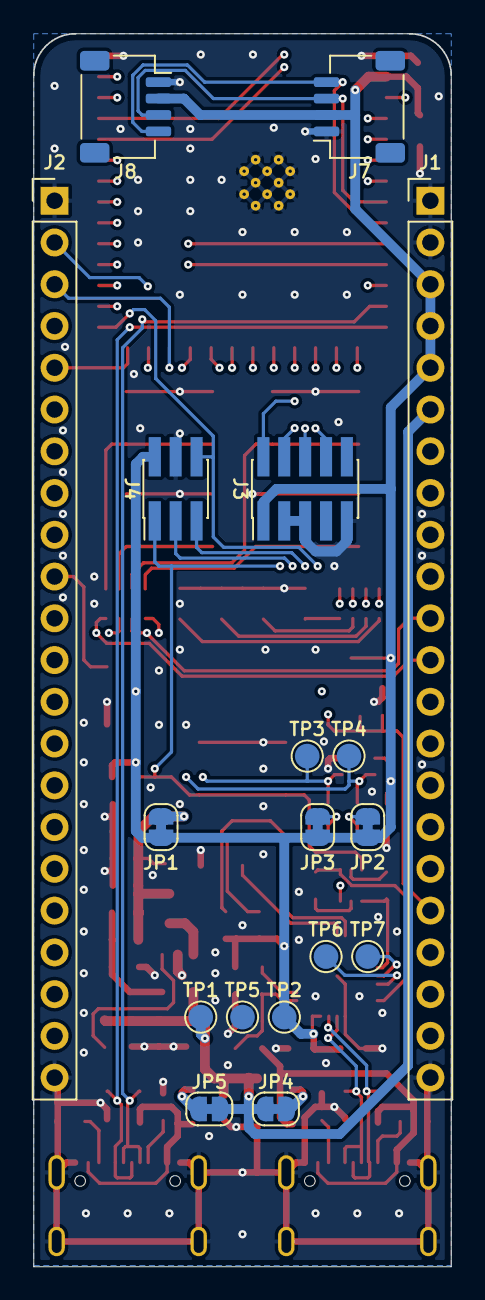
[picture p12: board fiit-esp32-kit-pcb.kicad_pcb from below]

Board: 4 copper layers, 25.4 x 75.0 mm, 81 parts (18 on the bottom side), 75 nets.

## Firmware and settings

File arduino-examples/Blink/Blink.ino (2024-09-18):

uint8_t redPin = 7;
uint8_t greenPin = 6;
uint8_t yellowPin = 5;
uint8_t bluePin = 4;

// the setup function runs once when you press reset or power the board
void setup() {
  // initialize all LED pins as an output
  pinMode(redPin, OUTPUT);
  pinMode(greenPin, OUTPUT);
  pinMode(yellowPin, OUTPUT);
  pinMode(bluePin, OUTPUT);
}

// the loop function runs over and over again forever
void loop() {
  // turn on all LEDs
  digitalWrite(redPin, HIGH);
  digitalWrite(greenPin, HIGH);
  digitalWrite(yellowPin, HIGH);
  digitalWrite(bluePin, HIGH);

  delay(1000);                       // wait for a second

  // turn off all LEDs
  digitalWrite(redPin, LOW);
  digitalWrite(greenPin, LOW);
  digitalWrite(yellowPin, LOW);
  digitalWrite(bluePin, LOW);

  delay(1000);                       // wait for a second
}

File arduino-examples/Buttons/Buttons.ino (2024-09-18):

uint8_t buttonPins[] = {1, 2, 47, 48};
uint8_t ledPins[] = {7, 6, 5, 4};
bool buttonState;

// the setup function runs once when you press reset or power the board
void setup() {
  for(int i = 0; i < 4; ++i)
  {
    // initialize all button pins as an output, enable PULL-UP resistor
    pinMode(buttonPins[i], INPUT_PULLUP);

    // initialize all LED pins as an output
    pinMode(ledPins[i], OUTPUT);
  }
}

// the loop function runs over and over again forever
void loop() {
  for(int i = 0; i < 4; ++i)
  {
    // read button state
    buttonState = digitalRead(buttonPins[i]);

    // negate buttonState because of negative logic (pressed = 0, not pressed = 1)
    buttonState = !buttonState;

    // write buttonState to LED
    digitalWrite(ledPins[i], buttonState);
  }
}

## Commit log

2024-07-21 added schematic drawing
    [fiit-esp32-kit-pcb.kicad_pcb, fiit-esp32-kit-pcb.kicad_sch, peripherals.kicad_sch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]
2024-07-21 added footprint library
2024-07-21 footprints assignment
    [fiit-esp32-kit-pcb.kicad_sch, peripherals.kicad_sch, usb_serial.kicad_sch]
2024-07-21 updated manufacturer part numbers
    [fiit-esp32-kit-pcb.kicad_sch, peripherals.kicad_sch, usb_serial.kicad_sch]
2024-07-21 component placement
    [fiit-esp32-kit-pcb.kicad_pcb, fiit-esp32-kit-pcb.kicad_sch, peripherals.kicad_sch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]
2024-07-30 updated components placement (unrouted 237)
    [fiit-esp32-kit-pcb.kicad_pcb, fiit-esp32-kit-pcb.kicad_sch, peripherals.kicad_sch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]
2024-07-30 added some tracks (unrouted 107)
    [fiit-esp32-kit-pcb.kicad_pcb, fiit-esp32-kit-pcb.kicad_sch, peripherals.kicad_sch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]
2024-07-30 added some tracks (unrouted 76)
    [fiit-esp32-kit-pcb.kicad_pcb]
2024-08-02 added some tracks (unrouted 0 !!!)
    [fiit-esp32-kit-pcb.kicad_pcb, fiit-esp32-kit-pcb.kicad_sch, usb_serial.kicad_sch]
2024-08-04 final improvements
    [fiit-esp32-kit-pcb.kicad_pcb]
2024-08-04 added gerber files
    [fiit-esp32-kit-pcb-B_Cu.gbl, fiit-esp32-kit-pcb-B_Mask.gbs, fiit-esp32-kit-pcb-B_Paste.gbp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]
2024-08-04 final changes
    [fiit-esp32-kit-pcb.kicad_pcb, fiit-esp32-kit-pcb.kicad_sch, peripherals.kicad_sch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]
2024-08-04 added schematic
